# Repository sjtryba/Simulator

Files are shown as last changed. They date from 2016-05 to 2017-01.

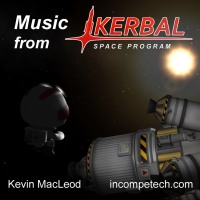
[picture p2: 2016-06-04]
music/Folder.jpg

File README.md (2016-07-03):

# Simulator
A simulator for NASA's Space Launch System

## Panels
6 panels make up the hardware of the user interface.

### Attitude Indicator
The attitude indicator is a que ball marked with latitude and longitude. Three omni-wheels mounted to continuous rotation servos control all three rotational degrees of freedom.

### Joystick and Throttle
A three axis joystick controls the attitude indicator. The throttle is a touch sensitive potentiometer. This panel also has buttons for RCS and SAS.

### Alarm Display
The alarm display shows the pilot anything that is going wrong.

### Alarm Puzzle
The alarm puzzle must be solved if the master alarm is triggered. If you take too long the ship will catch fire and eventually explode.

### Fuel Indicator
The fuel indicator shows the pilot the current levels of fuel and oxidizer for the current stage.

### Life Support Indicator
The life support indicator shows the oxygen, carbon dioxide, and water levels as well as the cabin pressure.

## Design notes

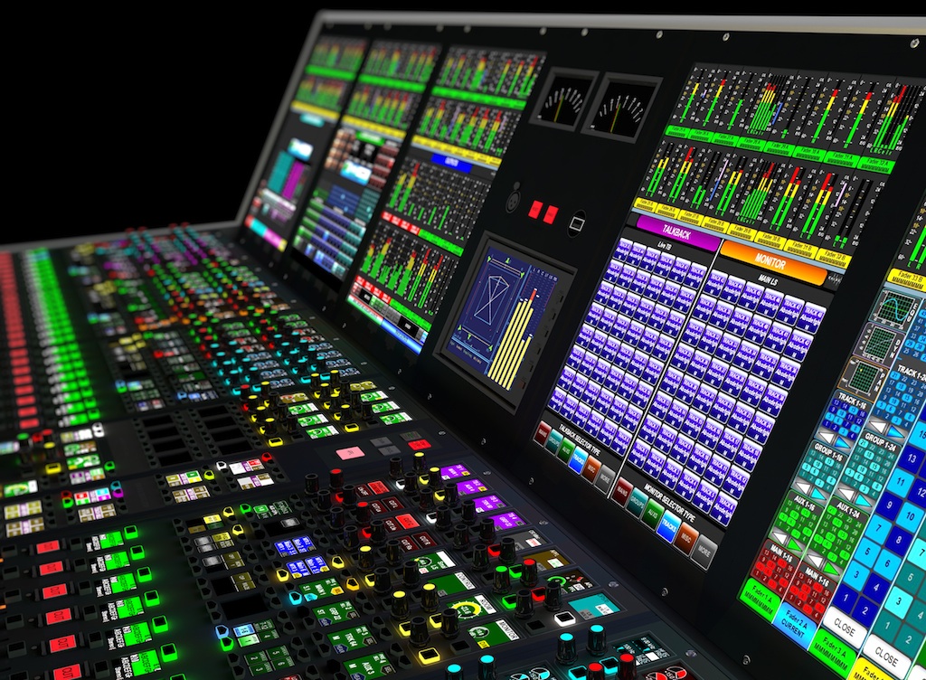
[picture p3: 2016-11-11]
documentation/Ideas/Calrec-Artemis-web.jpg

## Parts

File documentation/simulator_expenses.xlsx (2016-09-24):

Simulator Expenses |  |  |  |  |  |  |  | $1336.00
Received | Date | Quantity | Price Each | Price | Supplier | Part Number | Order Number | Link | Description
X | 2015-10-11 | 1 | $24.29 | $24.29 | Adafruit | 1586 | 895755-4862778484 | https://www.adafruit.com/products/1586 | NeoPixel Ring - 24 x WS2812 5050 RGB LED with Integrated Drivers
X | 2015-11-01 | 1 | $11.96 | $11.96 | McMaster Carr | 96385K68 | 1101STRYBA | http://www.mcmaster.com/#catalog/121/3572/=zphf98 | Abrasion-Resistant Natural Gum Rubber Ball, 2" Diameter, 45-55A Durometer
X | 2015-11-12 | 1 | $5.78 | $5.78 | Amazon |  | 102-1613341-3097840 | http://www.amazon.com/gp/product/B0060BCOPW?psc=1&redirect=true&ref_=oh_aui_detailpage_o00_s00 | Regulation Size 2 1/4" Pool Table Billiard Cue Ball
X | 2015-11-21 | 1 | $6.99 | $6.99 | Michaels |  |  |  | Spray Primer
X | 2015-11-21 | 1 | $6.17 | $6.17 | Michaels |  |  |  | Paint brushes
X | 2015-11-21 | 3 | $1.89 | $5.67 | Michaels |  |  |  | White, Blue and Brown Paint
X | 2015-12-04 | 1 | $5.16 | $5.16 | Amazon |  | 109-0000894-6228242 | http://www.amazon.com/gp/product/B00EVBNSYY?psc=1&redirect=true&ref_=oh_aui_detailpage_o00_s00 | Paint Pen
X | 2015-12-13 | 1 | $24.95 | $24.95 | Sparkfun | PRT-13144 | 2271088 | https://www.sparkfun.com/products/13144 | SparkFun Touch Potentiometer
X | 2015-12-13 | 1 | $4.95 | $4.95 | Sparkfun | COM-11966 | 2271088 | https://www.sparkfun.com/products/11966 | Metal Pushbutton - Momentary (16mm, Red)
X | 2015-12-13 | 1 | $4.95 | $4.95 | Sparkfun | COM-11967 | 2271088 | https://www.sparkfun.com/products/11967 | Metal Pushbutton - Momentary (16mm, Blue)
X | 2015-12-13 | 1 | $4.95 | $4.95 | Sparkfun | COM-11968 | 2271088 | https://www.sparkfun.com/products/11968 | Metal Pushbutton - Momentary (16mm, Green)
X | 2015-12-13 | 1 | $4.95 | $4.95 | Sparkfun | COM-11969 | 2271088 | https://www.sparkfun.com/products/11969 | Metal Pushbutton - Momentary (16mm, Yellow)
X | 2015-12-13 | 1 | $4.95 | $4.95 | Sparkfun | COM-11970 | 2271088 | https://www.sparkfun.com/products/11970 | Metal Pushbutton - Momentary (16mm, White)
X | 2015-12-13 | 1 | $4.53 | $4.53 | Sparkfun |  | 2271088 |  | Shipping
X | 2015-12-25 | 1 | $34.99 | $34.99 | Amazon | OM300B-M2 |  | http://www.amazon.com/gp/product/B00CS6O3SY?refRID=D66WDSZBJ34W8X71KMX7&ref_=pd_cart_vw_2_6_p#Ask | Analog 3-Axis Joystick
X | 2016-01-28 | 1 | $49.99 | $49.99 | Sparkfun | DEV-13724 | 2588949 | https://www.sparkfun.com/products/13724 | Raspberry Pi 2 - Model B (8GB Bundle)
X | 2016-01-28 | 3 | $13.95 | $41.85 | Sparkfun | ROB-0934 | 2588949 | https://www.sparkfun.com/products/9347 | Servo - Generic High Torque Full Rotation (Standard Size)
X | 2016-01-28 | 2 | $12.95 | $25.90 | Sparkfun | COM-11442 | 2588949 | https://www.sparkfun.com/products/11442 | SparkFun 7-Segment Serial Display - Blue
X | 2016-02-03 | 12 | $12.30 | $147.60 | Sparkfun | COM-11442 | 2657878 | https://www.sparkfun.com/products/11442 | SparkFun 7-Segment Serial Display - Blue
X | 2016-02-03 | 5 | $12.95 | $64.75 | Sparkfun | COM-11441 | 2657878 | https://www.sparkfun.com/products/11441 | SparkFun 7-Segment Serial Display - Red
X | 2016-02-03 | 1 | $39.95 | $39.95 | Amazon | CA-3602FFP |  | http://www.amazon.com/gp/product/B00BXF5HQ8?psc=1&redirect=true&ref_=oh_aui_detailpage_o00_s00 | Cyber Acoustics 30 Watt Powered Speakers with Subwoofer for PC and Gaming Systems
X | 2016-02-03 | 12 | $2.38 | $28.50 | Amazon | XB2-ED21 |  | http://www.amazon.com/gp/product/B0054UFAI8?psc=1&redirect=true&ref_=oh_aui_detailpage_o01_s00 | uxcell® On/Off Two 2 Position Rotary Select Selector Switch 1 NO 10A 600V AC
X | 2016-02-13 | 1 | $7.95 | $7.95 | Pololu | 1931 | 1J257685 | https://www.pololu.com/product/1931 | Male Crimp Pins for 0.1" Housings 100-Pack
X | 2016-02-13 | 10 | $0.68 | $6.80 | Pololu | 965 | 1J257686 | https://www.pololu.com/product/965 | 0.100" (2.54 mm) Breakaway Male Header: 1×40-Pin, Straight, Black
X | 2016-02-13 | 1 | $5.95 | $5.95 | Pololu | 1930 | 1J257684 | https://www.pololu.com/product/1930 | Female Crimp Pins for 0.1" Housings 100-Pack
X | 2016-02-13 | 1 | $4.45 | $4.45 | Pololu |  | 1J257686 |  | Shipping
X | 2016-02-13 | 2 | $0.79 | $1.58 | Pololu | 1902 | 1J257676 | https://www.pololu.com/product/1902 | 0.1" (2.54mm) Crimp Connector Housing: 1x3-Pin 25-Pack
X | 2016-02-13 | 2 | $0.69 | $1.38 | Pololu | 1901 | 1J257675 | https://www.pololu.com/product/1901 | 0.1" (2.54mm) Crimp Connector Housing: 1x2-Pin 25-Pack
X | 2016-02-13 | 1 | $1.19 | $1.19 | Pololu | 1909 | 1J257683 | https://www.pololu.com/product/1909 | 0.1" (2.54mm) Crimp Connector Housing: 1x10-Pin 5-Pack
X | 2016-02-13 | 2 | $0.59 | $1.18 | Pololu | 1900 | 1J257675 | https://www.pololu.com/product/1900 | 0.1" (2.54mm) Crimp Connector Housing: 1x1-Pin 25-Pack
X | 2016-02-13 | 1 | $1.09 | $1.09 | Pololu | 1908 | 1J257682 | https://www.pololu.com/product/1908 | 0.1" (2.54mm) Crimp Connector Housing: 1x9-Pin 5-Pack
X | 2016-02-13 | 1 | $0.99 | $0.99 | Pololu | 1907 | 1J257681 | https://www.pololu.com/product/1907 | 0.1" (2.54mm) Crimp Connector Housing: 1x8-Pin 10-Pack
X | 2016-02-13 | 1 | $0.89 | $0.89 | Pololu | 1906 | 1J257680 | https://www.pololu.com/product/1906 | 0.1" (2.54mm) Crimp Connector Housing: 1x7-Pin 10-Pack
X | 2016-02-13 | 1 | $0.79 | $0.79 | Pololu | 1905 | 1J257679 | https://www.pololu.com/product/1905 | 0.1" (2.54mm) Crimp Connector Housing: 1x6-Pin 10-Pack
X | 2016-02-13 | 1 | $0.69 | $0.69 | Pololu | 1904 | 1J257678 | https://www.pololu.com/product/1904 | 0.1" (2.54mm) Crimp Connector Housing: 1x5-Pin 10-Pack
X | 2016-02-13 | 1 | $0.59 | $0.59 | Pololu | 1903 | 1J257677 | https://www.pololu.com/product/1903 | 0.1" (2.54mm) Crimp Connector Housing: 1x4-Pin 10-Pack
X | 2016-03-01 | 4 | $59.80 | $59.80 | Adafruit | 1085 | 1032603-0233659072 | https://www.adafruit.com/products/1085 | 16-Bit ADC - 4 Channel with Programmable Gain Amplifier
X | 2016-03-01 | 1 | $19.90 | $19.90 | Adafruit | 904 | 1032603-0233659072 | https://www.adafruit.com/products/904 | High Side DC Current Sensor Breakout - 26V ±3.2A Max
X | 2016-03-01 | 1 | $9.56 | $9.56 | Adafruit |  | 1032603-0233659072 |  | Shipping
X | 2016-03-04 | 1 | $55.00 | $55.00 | Adafruit | 1996 | 1036714-8072516486 | https://www.adafruit.com/products/1996 | Element 14 BeagleBone Black Rev C - 4GB - Pre-installed Debian - Element 14 Version
X | 2016-03-04 | 1 | $9.95 | $9.95 | Adafruit | 572 | 1036714-8072516486 | https://www.adafruit.com/products/572 | Adafruit Proto Cape Kit for Beagle Bone & Beagle Bone Black
X | 2016-03-15 | 1 | $8.99 | 8.99 | Amazon |  | 115-9971758-8920211 | http://www.amazon.com/gp/product/B00GUO5WUI?psc=1&redirect=true&ref_=oh_aui_detailpage_o01_s00 | iMBAPrice® 12V DC Wall Power Adapter - 5.5mm x 2.1mm plug 1A(1000MA) UL Listed Power Supply
X | 2016-03-15 | 1 | $6.99 | 6.99 | Amazon |  | 115-9971758-8920211 | http://www.amazon.com/gp/product/B0060AU5MW?psc=1&redirect=true&ref_=oh_aui_detailpage_o01_s00 | BlueRigger High Speed Micro HDMI to HDMI cable with Ethernet (6 Feet)
X | 2016-03-23 | 1 | $19.65 | $19.65 | Digikey | 285-1890-ND | 1 | https://www.digikey.com/product-detail/en/tdk-lambda-americas-inc/LS25-5/285-1890-ND/2057039 | AC/DC CONVERTER 5V 25W
X | 2016-03-23 | 3 | $2.95 | $8.85 | Digikey | 1568-1209-ND | 1 | https://www.digikey.com/product-detail/en/sparkfun-electronics/BOB-12009/1568-1209-ND/5673795 | LOGIC LEVEL CONVERTER - BI-DIREC (x3)
X | 2016-03-23 | 1 | $21.96 | $21.96 | Digikey | CCM1383-ND | 1 | https://www.digikey.com/product-detail/en/te-connectivity-corcom-filters/PE0SSSS60/CCM1383-ND/260236 | CONN POWER ENTRY W/FILTER 6AMP
X | 2016-03-23 | 10 | $0.25 | $2.53 | Digikey | 277-11117-ND | 1 | https://www.digikey.com/product-detail/en/phoenix-contact/3240016/277-11117-ND/3603864 | CONN RING CIRC 16-20AWG M3 CRIMP
X | 2016-03-23 | 10 | $1.26 | $12.61 | Digikey | WM4314-ND | 1 | https://www.digikey.com/product-detail/en/molex-llc/0196001304/WM4314-ND/2421245 | 0.187" (4.75mm) Quick Connect Female 16-22 AWG Crimp Connector Fully Insulated
X | 2016-03-29 | 1 | $4.96 | $4.96 | Home Depot |  |  |  | 14 Awg Red Wire
X | 2016-03-29 | 1 | $4.96 | $4.96 | Home Depot |  |  |  | 14 Awg Black Wire
X | 2016-03-29 | 1 | $4.96 | $4.96 | Home Depot |  |  |  | 14 Awg White Wire
X | 2016-03-29 | 1 | $3.96 | $3.96 | Home Depot |  |  |  | 14-16 Awg 8-10 Stud Spade
X | 2016-03-29 | 1 | $3.96 | $3.96 | Home Depot |  |  |  | 10-12 Awg 8-10 Stud Spade
X | 2016-03-29 | 1 | $11.98 | $11.98 | Home Depot |  |  |  | 10-22 Awg 30A/600V 6 Circuit Terminal Block
X | 2016-03-29 | 1 | $6.99 | $6.99 | Home Depot |  |  |  | 10-22 Awg 30A/600V 8 Circuit Terminal Block
X | 2016-03-31 | 1 | $4.96 | $4.96 | Home Depot |  |  |  | 16 Awg Green Wire
X | 2016-04-20 | 1 | $9.95 | $9.95 | Digikey | 1568-1261-ND | 2 | https://www.digikey.com/product-detail/en/sparkfun-electronics/DEV-12774/1568-1261-ND/5762411 | SPARKFUN BEAGLEBONE BLACK PROTO
X | 2016-04-20 | 1 | $9.90 | $9.90 | Digikey | 1528-1365-ND | 2 | https://www.digikey.com/product-detail/en/adafruit-industries-llc/706/1528-1365-ND/5629413 | 46 Position Header Connector 0.100" (2.54mm) Through Hole Gold
X | 2016-05-01 | 1 | $59.63 | $59.63 | Adafruit | 1996 | 1094514-0385595948 | https://www.adafruit.com/products/1996 | Element 14 BeagleBone Black Rev C - 4GB - Pre-installed Debian - Element 14 Version
X | 2016-05-15 | 1 | $3.95 | $3.95 | Adafruit | 758 | 1106139-4977132431 | https://www.adafruit.com/products/758 | Premium Male/Male Jumper Wires - 40 x 6" (150mm)
X | 2016-05-15 | 1 | $3.95 | $3.95 | Adafruit | 759 | 1106139-4977132431 | https://www.adafruit.com/products/759 | Premium Male/Male Jumper Wires - 40 x 3" (75mm)
X | 2016-05-15 | 1 | $325.00 | $325.00 | Adafruit | 2131 | 1106139-4977132431 | https://www.adafruit.com/products/2131 | The EggBot Pro
X | 2016-09-03 | 2 | $12.95 | $25.90 | Sparkfun | 11441 | 2712146 | https://www.sparkfun.com/products/11441 | SparkFun 7-Segment Serial Display - Red
X | 2016-09-03 | 2 | $12.95 | $25.90 | Sparkfun | 11442 | 2712146 | https://www.sparkfun.com/products/11442 | SparkFun 7-Segment Serial Display - Blue

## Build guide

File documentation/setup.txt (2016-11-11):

# Update the Beablebone Black
sudo apt-get update

# Install all necessary modules in one sweep
sudo apt-get install cifs-utils build-essential python-dev python-setuptools python-pip python-smbus python-pygame -y

# Edit the fstab file to gain access to the shared simulator folder. This line should be commented out before the system is shutdown.
# It does not like to read this addition on boot.
sudo nano /etc/fstab
	append the file with:
//[IP ADDRESS]/simulator /home/debian/simulator cifs username=sjtry_000,password=[PASSWORD] 0 0

# Mount the shared folder to the Beaglebone Black
sudo mount -a

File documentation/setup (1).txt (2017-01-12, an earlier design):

sudo apt-get update
sudo apt-get install cifs-utils build-essential python-dev python-setuptools python-pip python-smbus -y
sudo apt-get install python-pygame
sudo nano /etc/fstab
	append the file with:
//192.168.0.17/simulator /home/debian/simulator cifs username=sjtry_000,password=[PASSWORD] 0 0
sudo mount -a

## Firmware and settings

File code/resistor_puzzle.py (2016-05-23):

from itertools import combinations
import random
import seven_segment_i2c
import Adafruit_GPIO as GPIO
import time


# ------------------------------------CONSTANTS----------------------------------
RESISTOR_VALUES = [1000.0, 1100.0, 1300.0,
                   2000.0, 2100.0, 2300.0,
                   3000.0, 3300.0, 3500.0]  # Resistor values in Ohms
# Location of resistors:
# 0 1 2 (parallel group 1)
# 3 4 5 (parallel group 2)
# 6 7 8 (parallel group 3)


def set_goal(combos):
    """
    This function returns a random value from the input list
    :param combos: an array of possible circuit impedance
    """
    return random.choice(combos)


def load_combinations():
    """
    This function calculates the effective impedance for all possible combinations of the resistor puzzle.
    It also returns the error propagation for the given combinations.
    The puzzle consists of 3 groups of resistor in series. Each group has three resistor in parallel.
    """

    # ------------------------------------VARIABLES----------------------------------
    number_of_resistors = len(RESISTOR_VALUES)  # Number of resistors in the puzzle

    indices = [x for x in range(number_of_resistors)]

    reciprocals = [1 / RESISTOR_VALUES[i] for i in range(number_of_resistors)]  # Reciprocal resistances (1/R)

    index_combinations = []  # Initiate a list for the index combinations

    # ------------------------------------COMBINATIONS----------------------------------
    for i in range(number_of_resistors):  # Fill in the list containing all the combinations of the resistors indices
        index_combinations.extend(combinations(indices, i + 1))

    number_of_combinations = len(index_combinations)  # Number of combinations of resistors

    # Make a list of reciprocal impedance.
    # 0 is for the first parallel group,
    # 1 is for the second parallel group,
    # 2 is for the third parallel group
    reciprocal_impedance = [[0 for x in range(3)] for x in range(number_of_combinations)]

    # Fill in the impedance lists
    for i in range(number_of_combinations):  # Loop through each combination
        for j in range(number_of_resistors):  # Loop through each resistor
            if j in index_combinations[i]:  # If the resistor is 'ON' include it in the impedance
                reciprocal_impedance[i][int(j / 3)] += reciprocals[j]

    # ------------------------------------IMPEDANCE----------------------------------
    # Only count the impedance combination that make a complete circuit
    # Specifically this means having at least one switch in each parallel combination closed
    impedance = []  # Impedance
    equivalent_impedance_index_combinations = []
    for i in range(number_of_combinations):  # Loop through each combination
        if ((indices[0] in index_combinations[i] or indices[1] in index_combinations[i] or indices[2] in
            index_combinations[i]) and  # If there is a closed switch in the first group
                (indices[3] in index_combinations[i] or indices[4] in index_combinations[i] or indices[5] in
                    index_combinations[i]) and  # If there is a closed switch in the second group
                (indices[6] in index_combinations[i] or indices[7] in index_combinations[i] or indices[8] in
                    index_combinations[i])):  # If there is a closed switch in the third group
            r_temp = [0, 0, 0]
            for j in range(3):
                r_temp[j] = 1 / reciprocal_impedance[i][j]
            impedance.append(r_temp)  # Add the impedance to the list
            equivalent_impedance_index_combinations.append(index_combinations[i])

    equivalent_impedance = [0 for x in range(len(impedance))]  # Equivalent impedance of the entire circuit

    for i in range(len(impedance)):
        equivalent_impedance[i] = sum(impedance[i])  # Sum the parallel impedance
    # equivalent_impedance = sorted(equivalent_impedance)
    return equivalent_impedance


def main():
    # Generate the display objects
    goal_display = seven_segment_i2c.SevenSegmentDisplay(address=0x71)
    actual_display = seven_segment_i2c.SevenSegmentDisplay(address=0x72)
    parallel_group_display0 = seven_segment_i2c.SevenSegmentDisplay(address=0x73)
    parallel_group_display1 = seven_segment_i2c.SevenSegmentDisplay(address=0x74)
    parallel_group_display2 = seven_segment_i2c.SevenSegmentDisplay(address=0x75)

    # Set up the input pins for the switches
    pins = ["P8_7",  "P8_9",  "P8_11",
            "P8_8",  "P8_10", "P8_12",
            "P8_14", "P8_16", "P8_18"]

    open_loop_val = "0000"

    switches = [GPIO.get_platform_gpio()] * len(pins)
    for i in range(len(switches)):
        switches[i].setup(pins[i], GPIO.IN)

    goal = int(set_goal(load_combinations()))
    print(goal)
    goal_display.write_int(goal)

    while True:
        # Read all the switches.
        switch_states = [0] * len(switches)
        resistance = [0, 0, 0]
        for i in range(len(switches)):
            # Read the specified ADC channel using the previously set gain value.
            switch_states[i] = switches[i].input(pins[i])

        if ((switch_states[0] or switch_states[1] or switch_states[2]) and  # A closed switch in the first group
                (switch_states[3] or switch_states[4] or switch_states[5]) and  # A closed switch in the second group
                (switch_states[6] or switch_states[7] or switch_states[8])):  # A closed switch in the third group
            # The circuit is complete and we should calculate the impedance
            for i in range(0, 3):
                if switch_states[i]:
                    resistance[0] += 1 / RESISTOR_VALUES[i]  # calculate the resistance of the first group
            for i in range(3, 6):
                if switch_states[i]:
                    resistance[1] += 1 / RESISTOR_VALUES[i]  # calculate the resistance of the second group
            for i in range(6, 9):
                if switch_states[i]:
                    resistance[2] += 1 / RESISTOR_VALUES[i]  # calculate the resistance of the third group
            # Display the resistance values
            for i in range(len(resistance)):
                resistance[i] = int(1 / resistance[i])
            print(resistance)
            print(sum(resistance))
            parallel_group_display0.write_int(resistance[0])
            parallel_group_display1.write_int(resistance[1])
            parallel_group_display2.write_int(resistance[2])
            actual_display.write_int(sum(resistance))
        else:
            # The circuit is NOT complete and we should print the open loop values to the displays
            actual_display.write_int(open_loop_val)
            parallel_group_display0.write_int(open_loop_val)
            parallel_group_display1.write_int(open_loop_val)
            parallel_group_display2.write_int(open_loop_val)

        # Print the ADC values.
        # print('| {0:>1} | {1:>1} | {2:>1} | {3:>6} | {4:>1} | {5:<6} | {6:>1} | {7:>1} | {8:>1} |'.format(*switch_states))
        # Pause for half a second.
        time.sleep(0.5)

if __name__ == '__main__':
    main()

"""
    # ------------------------------------ERROR-PROPAGATION----------------------------------
    # We're looking for the error propagation in the combination calculation.
    # We start by finding the partial derivatives of the equivalent resistance equation with respect to each resistor.

    denominator = [0 for i in range(number_of_resistors)]
    numerator = [0 for i in range(number_of_resistors)]

    for i in range(number_of_resistors):
        if 0 <= i < 3:
            denominator[i] = (resistor_values[0] * resistor_values[1] +
                              resistor_values[0] * resistor_values[2] +
                              resistor_values[1] * resistor_values[2]) ^ 2
            if i == 0:
                numerator[i] = resistor_values[1] ^ 2 * resistor_values[2] ^ 2
            elif i == 1:
                numerator[i] = resistor_values[0] ^ 2 * resistor_values[2] ^ 2
            elif i == 2:
                numerator[i] = resistor_values[0] ^ 2 * resistor_values[1] ^ 2

        elif 3 <= i < 6:
            denominator[i] = (resistor_values[3] * resistor_values[4] +
                              resistor_values[3] * resistor_values[5] +
                              resistor_values[4] * resistor_values[5]) ^ 2
            if i == 3:
                numerator[i] = resistor_values[4] ^ 2 * resistor_values[5] ^ 2
            elif i == 4:
                numerator[i] = resistor_values[3] ^ 2 * resistor_values[5] ^ 2
            elif i == 5:
                numerator[i] = resistor_values[3] ^ 2 * resistor_values[4] ^ 2

        elif 6 <= i < 9:
            denominator[i] = (resistor_values[6] * resistor_values[7] +
                              resistor_values[6] * resistor_values[8] +
                              resistor_values[7] * resistor_values[8]) ^ 2
            if i == 6:
                numerator[i] = resistor_values[7] ^ 2 * resistor_values[8] ^ 2
            elif i == 7:
                numerator[i] = resistor_values[6] ^ 2 * resistor_values[8] ^ 2
            elif i == 8:
                numerator[i] = resistor_values[6] ^ 2 * resistor_values[7] ^ 2

    derivative = [0 for i in range(number_of_resistors)]
    for i in range(number_of_resistors):
        derivative[i] = numerator[i] / denominator[i]
    print(derivative)
    print(equivalent_impedance_index_combinations[0:8])
    print(equivalent_impedance[0:8])

# was working on the error propagation. I have the derivatives calculated. now we need to create the square root term
# including only those terms used and the resistors connected to the circuit.
"""

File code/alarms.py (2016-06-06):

import pygame


class Alarm:
    def __init__(self, tier, trigger_probability, damage_constant, resolution, sound_file_name, activate=False, silence=False):
        pygame.init()
        pygame.mixer.init()
        self.tier = tier
        self.trigger_probability = trigger_probability
        self.damage_constant = damage_constant
        self.resolution = resolution
        self.sound = pygame.mixer.Sound(sound_file_name)
        self.activate = activate
        self.silence = silence

    def trigger(self):
        # Trigger the alarm
        self.activate = True
        print("triggered")

        # If the alarm is not silenced, play the alarm sound
        if self.silence is False:
            self.sound.play()
            print("playing sound")

    def mute(self):
        # Mute the alarm
        self.silence = True

    def update(self):
        if self.activate:
            if pygame.mixer.get_busy():
                if self.silence:
                    pygame.mixer.stop()
            else:
                if self.silence is False:
                    self.sound.play()

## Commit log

2016-05-23 Uploading /documentation directory
    Initial documentation upload
    [Resistor Puzzle.fzz, Simulator 0.1.fzz, Simulator 0.3.fzz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]
2016-05-23 Documentation Organization
    Organized the /documentation directory. Added a folder for spec sheets
    and a folder for fritzing. Deleted an old Pi header picture.
    [Resistor Puzzle.fzz, Simulator 0.1.fzz, Simulator 0.3.fzz]
2016-05-23 Expenses Update
    Added EggBot order to expenses spreadsheet
    [simulator_expenses.xlsx]
2016-05-30 Comments in resistor_puzzle_simple
    Cleaning up resistor_puzzle_simple a bit. Removed several commented
    print commands used for debugging.
    Added comments
2016-05-30 Added Alarm class
    Currently, the alarm class is in it's own library. This will change
    eventually once I decide where it fill finally live.
2016-06-04 Picking Rocket Sound
    Grouping rocket sounds for each stage, the SRBs, and the separation.
    Removed many .ogg files. I'll create them again when I finalize the .wav
    files.
2016-06-04 Mixing Ignition Sounds
    Mixed ignition sounds for all stages and removed supporting files from
    the stage directories.
2016-06-06 Playing around with pygame.mixer.Sound
    Finally got pygame.mixer.Sound to play sound effects. Apparently, you
    have to initialize pygame and open a window before you can play sounds.
    Also, I started playing with the EggBot. The first print showed that
    text converts to paths as outlines and not centerlines. But there is an
    extension to EggBot that works around this called Hershey Text.
2016-07-03 Scope update, music, and flashing displays
    Updates to the READ ME file to better define the scope of the project.
    I also found some more music files that I like. The 'That's correct' bit
    has a good radio chatter part.
    I also included the Adafruit_PureIO library. Somewhere between the last
    test of the resistor puzzle and the current test the SevenSegment
    library broke and the PureIO library fixes it.
    I also added flashing of the displays for the resistor puzzle when the
    solution is found. The puzzle also breaks out of the loop when the
    solution is found.
    [resistor_puzzle_simple.py, seven_segment_i2c.py]
2016-09-24 Update to resistor_puzzle_simple.py
    Removed a few lines of code that were commented out. It's better to use
    version control software than to commnet out lines of code.
2016-09-24 simulator_expenses Update
    Added columns for 'quantity' and 'price each'.
    Added items to expense sheet.
    [simulator_expenses.xlsx]
2016-10-31 3D Modelling
    Update resistor puzzle panel and serial 7 segment display
